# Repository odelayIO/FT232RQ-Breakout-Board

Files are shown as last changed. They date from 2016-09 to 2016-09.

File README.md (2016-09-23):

##### View on [gh-page](https://odelayio.github.io/FT232RQ-Breakout-Board/)

# FTDI FT232RQ Breakout Board with Variable LDO for VIO

## Board Features:

- Capability to configure microcontrollers directly (e.g. CC430F5137) 
-	Configurable VCCIO between 1.8V to 5V using on-board LDO
-	Data Rate Max 3,000,000 BAUD (FTDI FT232R Chip)
-	Route the RTS and DTR to a header for easy mode as a Programmer
- TX and RX LED (Red/Green)
-	Small form factor

<br>
<br>
Layout
Layout

<br>
<br>
   
## Reflowing QFN-32 FTDI FT232RQ Chip:

First attempt to reflow a QFN-32 device to a board without purchasing expensive equipment.  I used a hot air gun that I purchased on Amazon for $14 ( TruePower 01-0712 Mini Heat Gun, Blue).  I also used solder paste that melts at 183C degrees.  

###Applied the solder paste:
Paste
<br>

###Placed QFN-32 Device
Placed
<br>

###Final Product being used to configure a CC430F5137 microcontroller
Layout

<br>
<br>

## Documents:

- Eagle_SCH_BRD_GERBER
  * Schematic, Layout and Gerber files
- FTDI_EEPROM_Configuration.xml
  * Configuration file used to configure the FT232RQ device
- Verify_Serial_Communications.py 
  * Simple Python script to test the serial communications between a reference USB design and the Unit Under Test (UUT)

<br>
<br>

## Parts List

| Part | Part Number | Unit Price | Notes | Link |
|---|---|---|---|---|
| USB Mini Connector | 151-1206-1-ND | $6.55 | 10 Connectors | http://www.digikey.com/product-detail/en/edac-inc/690-005-299-043/151-1206-1-ND/4312192 |
| FTDI FT232RQ | 768-1008-1-ND | $4.50 | 1 | http://www.digikey.com/product-detail/en/ftdi-future-technology-devices-international-ltd/FT232RQ-REEL/768-1008-1-ND/1836403 |
| LM317 | 768-1008-1-ND | $0.77 | In stock | http://www.digikey.com/product-detail/en/texas-instruments/LM317DCYR/296-12602-1-ND/443738 |
| 0.1uF, 0402, Cap | 490-6328-1-ND | $0.55 | 100 capacitor | http://www.digikey.com/product-detail/en/murata-electronics-north-america/GRM155R71C104KA88J/490-6328-1-ND/3845525 |
| 10uF, 0805, Cap | 1276-6456-1-ND | $0.78 | 10 capacitor  | http://www.digikey.com/product-detail/en/samsung-electro-mechanics-america-inc/CL21A106KPFNNNG/1276-6456-1-ND/5958084 |
| 143 ohm, 0402 | YAG2980CT-ND | $0.48 | 100 resistors | http://www.digikey.com/product-detail/en/yageo/RC0402FR-07143RL/YAG2980CT-ND/5281845 |
| 240 ohm, 0402 | 311-240JRCT-ND | $0.47 | 100 resistors | http://www.digikey.com/product-detail/en/yageo/RC0402JR-07240RL/311-240JRCT-ND/729393 |
| 392 ohm, 0402 | YAG3145CT-ND | $0.48 | 100 resistors | http://www.digikey.com/product-detail/en/yageo/RC0402FR-07392RL/YAG3145CT-ND/5282010 |
| 1k ohm, 0402 | 311-1.0KJRCT-ND | $0.47 | 100 resistors | http://www.digikey.com/product-detail/en/yageo/RC0402JR-071KL/311-1.0KJRCT-ND/729355 |
| Red LED | SML-D12V1WT86CT-ND | $1.71 | 10 LEDs | http://www.digikey.com/product-detail/en/rohm-semiconductor/SML-D12V1WT86/SML-D12V1WT86CT-ND/5843857 |
| Yellow/Green LED | SML-D12M1WT86CT-ND | $1.71 | 10 LEDs | http://www.digikey.com/product-detail/en/rohm-semiconductor/SML-D12M1WT86/SML-D12M1WT86CT-ND/5843861 |
| PCB Fab | 2 layer prototype  | $5.00 | 3 copies | http://docs.oshpark.com/services/two-layer/ |
| | | | | |

<br>
<br>

## Additional Information:
- Fab board at [https://oshpark.com/](https://oshpark.com/)
  - Gerber Zip Package was used to fab board

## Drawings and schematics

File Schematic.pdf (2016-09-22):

A

A

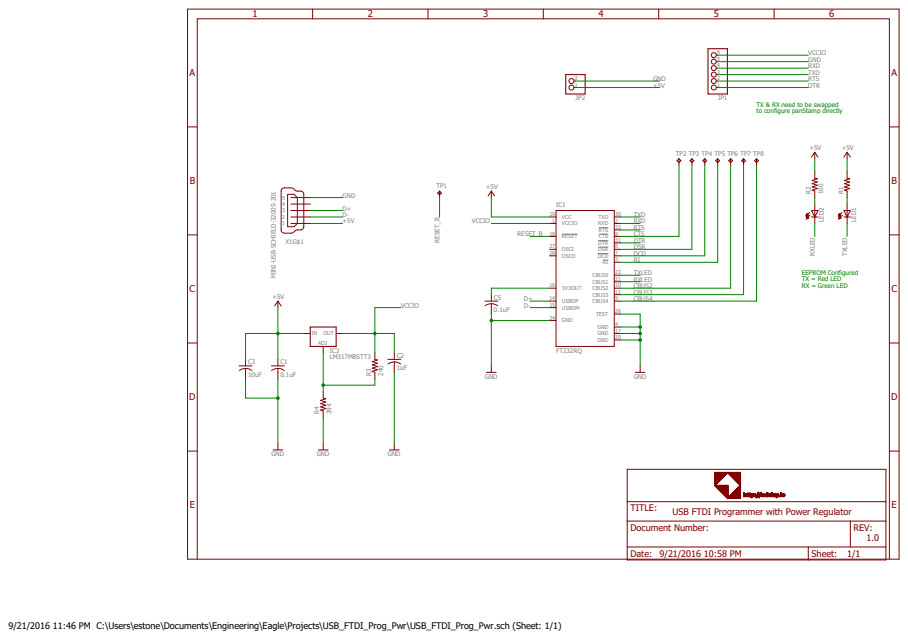
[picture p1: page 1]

TITLE:
USB FTDI Programmer with Power Regulator
Document Number:

9/21/2016 11:46 PM C:\Users\estone\Documents\Engineering\Eagle\Projects\USB_FTDI_Prog_Pwr\USB_FTDI_Prog_Pwr.sch (Sheet: 1/1)

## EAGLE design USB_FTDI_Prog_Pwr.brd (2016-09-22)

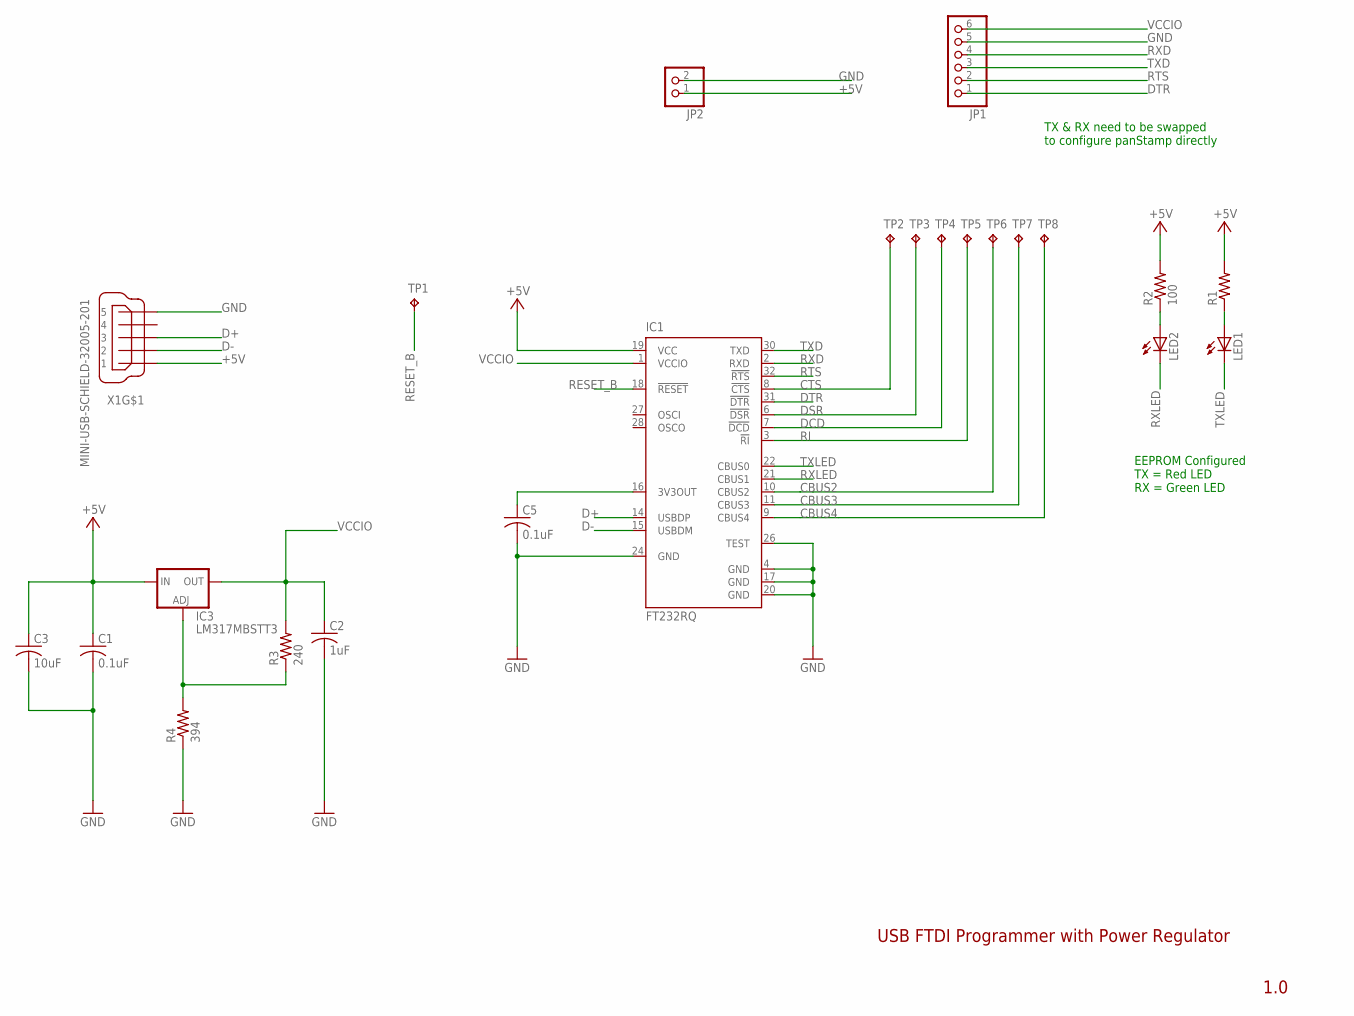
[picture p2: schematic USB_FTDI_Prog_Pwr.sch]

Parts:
C1, C5: 0.1uF; C0402
C2: 1uF; C0402
C3: 10uF; C0603
IC1: FT232RQ; QFN32
IC3: LM317MBSTT3; SOT223
JP1: PINHD-1X6; 1X06
JP2: PINHD-1X2; 1X02
LED1, LED2: LEDCHIP-LED0603; CHIP-LED0603
R1: R-US_R0402; R0402
R2: 100; R0402
R3: 240; R0402
R4: 394; R0402
TP1, TP2, TP3, TP4, TP5, TP6, TP7, TP8: TPB1,27; B1,27
X1: MINI-USB-SCHIELD-32005-201; 32005-201

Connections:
+5V: C1.1, C3.1, IC1.19 (VCC), IC3.3 (IN), JP2.1, R1.2, R2.2, X1.1
CBUS2: IC1.10 (CBUS2), TP6.TP
CBUS3: IC1.11 (CBUS3), TP7.TP
CBUS4: IC1.9 (CBUS4), TP8.TP
CTS: IC1.8 (!CTS), TP2.TP
D+: IC1.14 (USBDP), X1.3
D-: IC1.15 (USBDM), X1.2
DCD: IC1.7 (!DCD), TP4.TP
DSR: IC1.6 (!DSR), TP3.TP
DTR: IC1.31 (!DTR), JP1.1
GND: C1.2, C2.2, C3.2, C5.2, IC1.4 (GND), IC1.17 (GND), IC1.20 (GND), IC1.24 (GND), IC1.26 (TEST), JP1.5, JP2.2, R4.1, X1.5
unnamed: LED1.A, R1.1
unnamed: IC3.1 (ADJ), R3.1, R4.2
unnamed: C5.1, IC1.16 (3V3OUT)
unnamed: LED2.A, R2.1
RESET_B: IC1.18 (!RESET), TP1.TP
RI: IC1.3 (!RI), TP5.TP
RTS: IC1.32 (!RTS), JP1.2
RXD: IC1.2 (RXD), JP1.4
RXLED: IC1.21 (CBUS1), LED2.C
TXD: IC1.30 (TXD), JP1.3
TXLED: IC1.22 (CBUS0), LED1.C
VCCIO: C2.1, IC1.1 (VCCIO), IC3.4 (OUT), JP1.6, R3.2

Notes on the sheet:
USB FTDI Programmer with Power Regulator
1.0
EEPROM Configured TX = Red LED RX = Green LED
TX & RX need to be swapped to configure panStamp directly

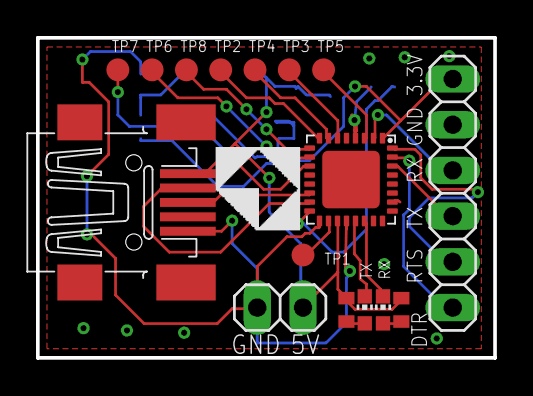
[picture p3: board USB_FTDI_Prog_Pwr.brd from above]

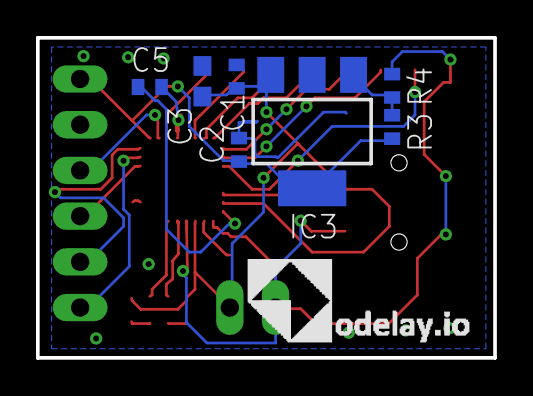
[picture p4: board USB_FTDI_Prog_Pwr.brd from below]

Board: 2 copper layers, 25.4 x 17.8 mm, 23 parts (7 on the bottom side), 23 nets.

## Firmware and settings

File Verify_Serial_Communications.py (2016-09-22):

#############################################################################################
#############################################################################################
#
#   The MIT License (MIT)
#   
#   Copyright (c) 2016 http://odelay.io 
#   
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
#   Contact : <everett@odelay.io>
#
#   Description: Created a quick script to check serial power between two boards.
#   
#   Version History:
#   
#       Date        Description
#     -----------   -----------------------------------------------------------------------
#      20SEP2016     Original Creation
#
#############################################################################################
#############################################################################################

import serial
import string
import random
from time import gmtime, strftime
import time

#VERBOSE         = True
VERBOSE         = False

#baudrate        = 9600
baudrate        = 115200
#baudrate        = 960000
charLen         = 256
loopLen         = 1024

uutUSB          = serial.Serial()
uutUSB.port     = "COM13"
uutUSB.baudrate = baudrate
uutUSB.timeout  = .2
uutUSB.open()

refUSB          = serial.Serial()
refUSB.port     = "COM10"
refUSB.baudrate = baudrate
refUSB.timeout  = .2
refUSB.open()

#--------------------------------------------------------------------------
# Grab time at start of test
#--------------------------------------------------------------------------
start_time = time.time()

print "\n\n"
print "Test Started : " + str(strftime("%Y-%m-%d %H:%M:%S", gmtime()))

#--------------------------------------------------------------------------
# Funcation to create the string (found on web, unknown source)
#--------------------------------------------------------------------------
def randString(size=1024, chars=string.ascii_uppercase + string.digits):
  return ''.join(random.choice(chars) for _ in range(size))

#--------------------------------------------------------------------------
# Check UUT receiver
#--------------------------------------------------------------------------
p_recv = 0
f_recv = 0
for x in range(0,loopLen):

  if(VERBOSE):
    print "Iteration: " + str(x)

  a = randString(charLen) + "\n"
  refUSB.write(a);
  b = uutUSB.readline()
  
  if(VERBOSE):
    print "Receiving " + str(charLen) + " characters from UUT"
  
  if(a == b):
    if(VERBOSE):
      print "Success."
    p_recv = p_recv + 1
  else:
    if(VERBOSE):
      print "Failed."
    f_recv = f_recv + 1
 
  if(VERBOSE):
    print "SENT: " + str(a) + "RECV: " + str(b)
    print "-------------------------------------\n"


#--------------------------------------------------------------------------
# Check UUT transmitter
#--------------------------------------------------------------------------
p_send = 0
f_send = 0
for x in range(0,loopLen):

  if(VERBOSE):
    print "Iteration: " + str(x)
  a = randString(charLen) + "\n"
  uutUSB.write(a);
  b = refUSB.readline()

  if(VERBOSE):
    print "Sending " + str(charLen) + " characters from UUT"

  if(a == b):
    if(VERBOSE):
      print "Success."
    p_send = p_send + 1
  else:
    if(VERBOSE):
      print "Failed."
    f_send = f_send + 1

  if(VERBOSE):
    print "SENT: " + str(a) + "RECV: " + str(b)
    print "-------------------------------------\n"

elapsed_time = time.time() - start_time

#--------------------------------------------------------------------------
# Print results
#--------------------------------------------------------------------------
print "Test Ended   : " + str(strftime("%Y-%m-%d %H:%M:%S", gmtime()))
print "\n"
print "  BAUD Rate          = " + str(baudrate)
print "  Message Size       = " + str(charLen)
print "  Number of Messages = " + str(loopLen)
print "\n"
print "  Elapsed Time       = " + str(elapsed_time)
print "  Sending characters from UUT"
print "    Number of Success  = " + str(p_send)
print "    Number of Fails    = " + str(f_send)
print "  Receiving characters from UUT"
print "    Number of Success  = " + str(p_recv)
print "    Number of Fails    = " + str(f_recv)
print "\n"

uutUSB.close()
refUSB.close()
